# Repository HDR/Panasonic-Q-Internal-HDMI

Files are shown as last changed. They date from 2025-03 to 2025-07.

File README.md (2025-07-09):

# Panasonic Q Internal HDMI



Please consider supporting me on [ko-fi](https://ko-fi.com/martinrefseth), i generally don't make money on projects like this.

A drop-in plug & play GCPlug based HDMI mod for the Panasonic Q

# Ordering the PCB

## **With Assembly**

### PCBWay
1. Navigate to the [PCBWay Shared Projects page](https://www.pcbway.com/project/shareproject/Panasonic_Q_Drop_in_Internal_HDMI_Mod_c8eb0727.html)
2. Select `PCB+Assembly`
3. Click `Add to cart`
4. Set assembly quantity to 1 (otherwise, the assembly cost rises from 29 USD to 88 USD)
5. Select any solder mask, silkscreen, and surface finish
6. Click `Submit`

## **Without Assembly**

#### PCBWay
1. Navigate to the [PCBWay Shared Projects page](https://www.pcbway.com/project/shareproject/Panasonic_Q_Drop_in_Internal_HDMI_Mod_c8eb0727.html)
2. Select `Only PCB`
3. Select any color, silkscreen, and finish
4. Click `Submit`

#### JLCPCB
1. Navigate to [JLCPCB's order page](https://cart.jlcpcb.com/quote)
2. Click `Add gerber file` and upload `Panasonic Q Internal HDMI.zip`
3. Select 1.6mm Thickness and any color, silkscreen and finish you want

# Ordering the printed pieces
#### PCBWay
1. Navigate to the [PCBWay Shared Projects page](https://www.pcbway.com/project/shareproject/Panasonic_Q_Drop_in_Internal_HDMI_Mod_c8eb0727.html)
2. Scroll down to `CAD-Custom parts and enclosures`
3. Click the shopping cart button
4. Select `Resin`and pick your desired material
5. Change Product Desc to `DIY Entertainment >> Gaming Enclosure (HSCode:950490)`
6. Click `Submit Request`
7. Repeat for the other piece

#### JLCPCB
1. Navigate to [JLCPCB's 3D print order page](https://jlc3dp.com/3d-printing-quote)
2. Click `Add 3D Files` and select `Panasonic Q HDMI Bracket.stl` & `Panasonic Q HDMI Cover.stl`
3. Select `SLA(Resin)` and pick your desired material
4. Set 'Product description' to `Enclosure, Block, Plate, Cylinder Category -> Plastic Enclosure - HS Code 392690`
5. Click `SAVE TO CART`

# Programming
### Tools & Software Needed
- A programmer like the CH341A/B
- The CH341A Programmer Software
-  [gcvideo-3.1-gcplug.zip](https://github.com/ikorb/gcvideo/releases/tag/GCVideo-DVI_release_3.1) from ikorb's gcvideo github page
### Flashing GCVideo
1. Bridge the jumper marked JP1
2. Connect the programmer to the HDMI board according to the pinout written on the programmer and the board
3. Open CH341A Programmer
4. Press the open button and select `gcvideo-dvi-gcplug-3.1-spirom-complete.bin`
5. Select Type: `25 SPI FLASH`, Manu: `GIGADEVICE` & Name: `GD25D40`
6. Press program
7. Press verify to make sure the firmware was written correctly
8. Remove the bridge on JP1

# Parts Overview
## Hardware Parts
```
1x Panasonic Q HDMI Bracket
1x Panasonic Q HDMI Cover
2x M2x6 Screws
1x M3x8 Screw
2x M2x3x3.2mm Threaded insert
1x M3x6x4.5mm threaded insert
```

## Board Parts
| Designator | Qty | Part Number | Package | Description | LCSC Part# |
|---|-----|---|---|---|---|
| C1 | 1 | GRM155R61E225KE11D | 0402 | 2.2uF Capacitor | C385032 |
| C2 | 1 | CGA0402X5R475M250GT | 0402 | 4.7uF Capacitor | C6119795  |
| C3 | 1 | CL10A106MA8NRNC | 0603 | 10uF Capacitor | C96446 |
| C4, C5, C6, C7, C12, C13, C14 | 7 | GRM155R71H104KE14D | 0402 | 100nF Capacitor | C77020 |
| C8, C9, C10, C11 | 4 | GRM155R61E105KA12D | 0402 | 1uF Capacitor | C77009 |
| D1 | 1 | IRM-3638T | SIP-3-2.54mm | 38kHz Infrared Receiver | C16216 |
| J1 | 1 | 2086581001 | SMD | MOLEX 2086581001 HDMI Connector | C916313 |
| J2 | 1 | 1.0-22P CTSJ-H2.5 119 | SMD,P=1mm,Surface Mount，Right Angle | 22 Pin Top Contact 1mm Pitch Connector | C5373501  |
| J3 | 1 | | | 1x6 2.54mm Pin Header | |
| R1 | 1 | 0402WGJ0331TCE | 0402 | 330Ω Resistor | C12246 |
| R2 | 1 | RC0402FR-07220RL | 0402 | 220Ω Resistor | C112291 |
| R3, R4 | 2 | 0402WGJ0472TCE | 0402 | 4.7kΩ Resistor | C25940 |
| R5 | 1 | 0402WGF1800TCE | 0402 | 180Ω Resistor | C38941 |
| R6, R7 | 2 | RC0402FR-0710KL | 0402 | 10kΩ Resistor | C98220 |
| SW1 | 1 | B3U-1000P | SMD,2.5x3mm | Remote Programming Button | C231329 |
| U1 | 1 | XC3S200A-4VQG100C | TQFP-100(14x14) | XILINX FPGA | C1521645  |
| U2 | 1 | ZD25D40CNJGR | USON-8-EP(1.5x1.5) | SPI NOR Flash | C3646778  |
| U3 | 1 | SSPX3819M5-L-5-0 | SOT-23-5 | 5V Regulator | C20617302 |
| U4 | 1 | RT9013-12GB | SOT-23-5 | 1.2V Regulator | C58464 |

[**Interactive BOM**](https://martinrefseth.com/ibom/QInternalHDMI.html)

You can also upload `LCSC_BOM.xls` to [LCSC](https://www.lcsc.com/inquiry)

## Notes
- Make sure you hold the button on the board to bring up the remote programming menu BEFORE assembling your Panasonic Q (Save the settings in the menu after programming the remote)
- Cut the pin headers with a flush cutter before re-assembly, otherwise your disk assembly won't fit
- The cost with assembly from PCBWay should be around 78 USD
- HDMI output is for GC mode only
- Enhanced DVI needs to be turned on in the GCVideo settings for audio output

## Credits

ikorb - [gcvideo](https://github.com/ikorb/gcvideo)

citrus3000psi - [gcplug](https://www.reddit.com/r/Gamecube/comments/7gduxq/build_your_own_gcplug/)





https://github.com/user-attachments/assets/7356d1f4-85a7-4fde-a83c-853f3280a0fc

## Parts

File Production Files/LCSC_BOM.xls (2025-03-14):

Panasonic Q Internal HDMI Mod |  |  |  |  |  |  |  |  |  | LCSC BOM Quotation
 |  |  |  |  |  |  |  |  |  | BOM Date Created：19/02/25 02:33:42 |  |  |  | BOM Export Date: 13/03/25 04:52:43 |  |  |  | The matching result is a real-time query result, availability and prices may fluctuate. Backorder items are estimated prices for your reference, please submit "Create Quote" to get the real price. All information is provided "as is" and is subject to change without notice. Any use made of the information provided is without recourse to LCSC and at the user's risk.
 |  |  |  |  |  |  |  |  |  | EST TOTAL :$22.39 |  |  |  | Website：https://www.lcsc.com/bom | https://www.lcsc.com/bom | https://www.lcsc.com/bom | https://www.lcsc.com/bom
Uploaded data |  |  |  |  |  |  |  |  |  | LCSC Matching Results
LCSC# | Mfr. | Mrf# | Description | Package | Value | Customer Part Number | Quantity | Target Price(USD) | Target Lead Time(Business Days) | Mrf# | Mfr. | Order Qty. | Unit Price(USD) | Ext.Price(USD) | LCSC# | Package | Min | Mult | SPQ | Availability | Stock Status | Customer Notes | Description | Matched status | Product Link
C3646778 | Zetta | ZD25D40CNJGR | 4Mbit SPI 104MHz USON-8-EP(1.5x1.5) NOR FLASH ROHS | USON-8-EP(1.5x1.5) |  | - | 5 |  |  | ZD25D40CNJGR | Zetta | 5 | 0.0861 | 0.43 | C3646778 | USON-8-EP(1.5x1.5) | 5 | 5 | 3000 | 8590 | In Stock | U2 | 4Mbit SPI 104MHz USON-8-EP(1.5x1.5) NOR FLASH ROHS | Exact Matches | https://www.lcsc.com/product-detail/nor-flash_zetta-zd25d40cnjgr_C3646778.html
C916313 | MOLEX | 2086581001 | SMD HDMI Connectors ROHS | SMD |  | - | 1 |  |  | 2086581001 | MOLEX | 1 | 1.2666 | 1.27 | C916313 | SMD | 1 | 1 | 350 | 482 | In Stock | J1 | SMD HDMI Connectors ROHS | Exact Matches | https://www.lcsc.com/product-detail/hdmi-connectors_molex-2086581001_C916313.html
C16216 | Everlight Elec | IRM-3638T | 38kHz 6m 450uA 2.7V~5.5V SIP-3-2.54mm Infrared Remote Receiver (IRM) ROHS | SIP-3-2.54mm |  | - | 25 |  |  | IRM-3638T | Everlight Elec | 25 | 0.1653 | 4.13 | C16216 | SIP-3-2.54mm | 25 | 25 | 250 | 56075 | In Stock | D1 | 38kHz 6m 450uA 2.7V~5.5V SIP-3-2.54mm Infrared Remote Receiver (IRM) ROHS | Exact Matches | https://www.lcsc.com/product-detail/infrared-remote-receiver-irm_everlight-elec-irm-3638t_C16216.html
C5373501 | SHOU HAN | 1.0-22P CTSJ-H2.5 119 | Drawer Type -55â„ƒ~+85â„ƒ 22P Contact,Top Horizontal attachment 1mm SMD,P=1mm,Surface Mountï¼ŒRight Angle FFC, FPC (Flat Flexible) Connector Assemblies ROHS | SMD,P=1mm,Surface Mountï¼ŒRight Angle |  | - | 5 |  |  | 1.0-22P CTSJ-H2.5 119 | SHOU HAN | 5 | 0.1808 | 0.90 | C5373501 | SMD,P=1mm,Surface Mount，Right Angle | 5 | 5 | 20 | 790 | In Stock | J2 | Drawer Type -55℃~+85℃ 22P Contact,Top Horizontal attachment 1mm SMD,P=1mm,Surface Mount，Right Angle FFC, FPC (Flat Flexible) Connector Assemblies ROHS | Exact Matches | https://www.lcsc.com/product-detail/ffc-fpc-flat-flexible-connector-assemblies_shou-han-1-0-22p-ctsj-h2-5-119_C5373501.html
C20617302 | TECH PUBLIC | SPX3819M5-L-5-0 | 500mA 70dB@(1kHz) Fixed 5V Positive electrode SOT-23-5 Voltage Regulators - Linear, Low Drop Out (LDO) Regulators ROHS | SOT-23-5 |  | - | 5 |  |  | SPX3819M5-L-5-0 | TECH PUBLIC | 5 | 0.1223 | 0.61 | C20617302 | SOT-23-5 | 5 | 5 | 3000 | 8165 | In Stock | U3 | 500mA 70dB@(1kHz) Fixed 5V Positive electrode SOT-23-5 Voltage Regulators - Linear, Low Drop Out (LDO) Regulators ROHS | Exact Matches | https://www.lcsc.com/product-detail/voltage-regulators-linear-low-drop-out-ldo-regulators_tech-public-spx3819m5-l-5-0_C20617302.html
C58464 | Richtek Tech | RT9013-12GB | 500mA 50dB@(10kHz) Fixed 1.2V Positive electrode 5.5V SOT-23-5 Voltage Regulators - Linear, Low Drop Out (LDO) Regulators ROHS | SOT-23-5 |  | - | 5 |  |  | RT9013-12GB | Richtek Tech | 5 | 0.1366 | 0.68 | C58464 | SOT-23-5 | 5 | 5 | 3000 | 12850 | In Stock | U4 | 500mA 50dB@(10kHz) Fixed 1.2V Positive electrode 5.5V SOT-23-5 Voltage Regulators - Linear, Low Drop Out (LDO) Regulators ROHS | Exact Matches | https://www.lcsc.com/product-detail/voltage-regulators-linear-low-drop-out-ldo-regulators_richtek-tech-rt9013-12gb_C58464.html
C385032 | Murata Electronics | GRM155R61E225KE11D | 25V 2.2uF X5R Â±10% 0402 Multilayer Ceramic Capacitors MLCC - SMD/SMT ROHS | 0402 |  | - | 50 |  |  | GRM155R61E225KE11D | Murata Electronics | 50 | 0.0185 | 0.93 | C385032 | 0402 | 50 | 50 | 10000 | 353050 | In Stock | C1 | 25V 2.2uF X5R ±10% 0402 Multilayer Ceramic Capacitors MLCC - SMD/SMT ROHS | Exact Matches | https://www.lcsc.com/product-detail/multilayer-ceramic-capacitors-mlcc-smd-smt_murata-electronics-grm155r61e225ke11d_C385032.html
C6119795 | HRE | CGA0402X5R475M250GT | 25V 4.7uF X5R Â±20% 0402 Multilayer Ceramic Capacitors MLCC - SMD/SMT ROHS | 0402 |  | - | 50 |  |  | CGA0402X5R475M250GT | HRE | 50 | 0.0128 | 0.64 | C6119795 | 0402 | 50 | 50 | 10000 | 379000 | In Stock | C2 | 25V 4.7uF X5R ±20% 0402 Multilayer Ceramic Capacitors MLCC - SMD/SMT ROHS | Exact Matches | https://www.lcsc.com/product-detail/multilayer-ceramic-capacitors-mlcc-smd-smt_hre-cga0402x5r475m250gt_C6119795.html
C96446 | Samsung Electro-Mechanics | CL10A106MA8NRNC | 25V 10uF X5R Â±20% 0603 Multilayer Ceramic Capacitors MLCC - SMD/SMT ROHS | 0603 |  | - | 20 |  |  | CL10A106MA8NRNC | Samsung Electro-Mechanics | 20 | 0.0151 | 0.30 | C96446 | 0603 | 20 | 20 | 4000 | 1307720 | In Stock | C3 | 25V 10uF X5R ±20% 0603 Multilayer Ceramic Capacitors MLCC - SMD/SMT ROHS | Exact Matches | https://www.lcsc.com/product-detail/multilayer-ceramic-capacitors-mlcc-smd-smt_samsung-electro-mechanics-cl10a106ma8nrnc_C96446.html
C77020 | Murata Electronics | GRM155R71H104KE14D | 50V 100nF X7R Â±10% 0402 Multilayer Ceramic Capacitors MLCC - SMD/SMT ROHS | 0402 |  | - | 100 |  |  | GRM155R71H104KE14D | Murata Electronics | 100 | 0.0032 | 0.32 | C77020 | 0402 | 100 | 100 | 10000 | 6570400 | In Stock | C4,C5,C6,C7,C12,C13,C14 | 50V 100nF X7R ±10% 0402 Multilayer Ceramic Capacitors MLCC - SMD/SMT ROHS | Exact Matches | https://www.lcsc.com/product-detail/multilayer-ceramic-capacitors-mlcc-smd-smt_murata-electronics-grm155r71h104ke14d_C77020.html
C77009 | Murata Electronics | GRM155R61E105KA12D | 25V 1uF X5R Â±10% 0402 Multilayer Ceramic Capacitors MLCC - SMD/SMT ROHS | 0402 |  | - | 100 |  |  | GRM155R61E105KA12D | Murata Electronics | 100 | 0.0053 | 0.53 | C77009 | 0402 | 100 | 100 | 10000 | 640500 | In Stock | C8,C9,C10,C11 | 25V 1uF X5R ±10% 0402 Multilayer Ceramic Capacitors MLCC - SMD/SMT ROHS | Exact Matches | https://www.lcsc.com/product-detail/multilayer-ceramic-capacitors-mlcc-smd-smt_murata-electronics-grm155r61e105ka12d_C77009.html
C12246 | UNI-ROYAL(Uniroyal Elec) | 0402WGJ0331TCE | 62.5mW Thick Film Resistors 50V Â±100ppm/â„ƒ Â±5% 330Î© 0402 Chip Resistor - Surface Mount ROHS | 0402 |  | - | 100 |  |  | 0402WGJ0331TCE | UNI-ROYAL(Uniroyal Elec) | 100 | 0.0005 | 0.05 | C12246 | 0402 | 100 | 100 | 10000 | 286700 | In Stock | R1 | 1/16W Thick Film Resistors 50V ±100ppm/℃ ±5% 330Ω 0402 Chip Resistor - Surface Mount ROHS | Exact Matches | https://www.lcsc.com/product-detail/chip-resistor-surface-mount_uni-royal-uniroyal-elec-0402wgj0331tce_C12246.html
C112291 | YAGEO | RC0402FR-07220RL | 62.5mW Thick Film Resistors 50V Â±100ppm/â„ƒ Â±1% 220Î© 0402 Chip Resistor - Surface Mount ROHS | 0402 |  | - | 100 |  |  | RC0402FR-07220RL | YAGEO | 100 | 0.0007 | 0.07 | C112291 | 0402 | 100 | 100 | 10000 | 818900 | In Stock | R2 | 62.5mW Thick Film Resistors 50V ±100ppm/℃ ±1% 220Ω 0402 Chip Resistor - Surface Mount ROHS | Exact Matches | https://www.lcsc.com/product-detail/chip-resistor-surface-mount_yageo-rc0402fr-07220rl_C112291.html
C25940 | UNI-ROYAL(Uniroyal Elec) | 0402WGJ0472TCE | 62.5mW Thick Film Resistors 50V Â±100ppm/â„ƒ Â±5% 4.7kÎ© 0402 Chip Resistor - Surface Mount ROHS | 0402 |  | - | 100 |  |  | 0402WGJ0472TCE | UNI-ROYAL(Uniroyal Elec) | 100 | 0.0005 | 0.05 | C25940 | 0402 | 100 | 100 | 10000 | 1585300 | In Stock | R3,R4 | 1/16W Thick Film Resistors 50V ±100ppm/℃ ±5% 4.7kΩ 0402 Chip Resistor - Surface Mount ROHS | Exact Matches | https://www.lcsc.com/product-detail/chip-resistor-surface-mount_uni-royal-uniroyal-elec-0402wgj0472tce_C25940.html
C38941 | UNI-ROYAL(Uniroyal Elec) | 0402WGF1800TCE | 62.5mW Thick Film Resistors 50V Â±100ppm/â„ƒ Â±1% 180Î© 0402 Chip Resistor - Surface Mount ROHS | 0402 |  | - | 100 |  |  | 0402WGF1800TCE | UNI-ROYAL(Uniroyal Elec) | 100 | 0.0006 | 0.06 | C38941 | 0402 | 100 | 100 | 10000 | 183000 | In Stock | R5 | 1/16W Thick Film Resistors 50V ±100ppm/℃ ±1% 180Ω 0402 Chip Resistor - Surface Mount ROHS | Exact Matches | https://www.lcsc.com/product-detail/chip-resistor-surface-mount_uni-royal-uniroyal-elec-0402wgf1800tce_C38941.html
C60490 | YAGEO | RC0402FR-0710KL | 62.5mW Thick Film Resistors 50V Â±100ppm/â„ƒ Â±1% 10kÎ© 0402 Chip Resistor - Surface Mount ROHS | 0402 |  | - | 100 |  |  | RC0402FR-0710KL | YAGEO | 100 | 0.0006 | 0.06 | C60490 | 0402 | 100 | 100 | 10000 | 14827900 | In Stock | R6,R7 | 62.5mW Thick Film Resistors 50V ±100ppm/℃ ±1% 10kΩ 0402 Chip Resistor - Surface Mount ROHS | Exact Matches | https://www.lcsc.com/product-detail/chip-resistor-surface-mount_yageo-rc0402fr-0710kl_C60490.html
C1521645 | AMD/XILINX | XC3S200A-4VQG100C | TQFP-100(14x14) Programmable Logic Device (CPLDs/FPGAs) ROHS | TQFP-100(14x14) |  | - | 1 |  |  | XC3S200A-4VQG100C | AMD/XILINX | 1 | 10.5574 | 10.56 | C1521645 | TQFP-100(14x14) | 1 | 1 | 90 | 104 | In Stock | U1 | TQFP-100(14x14) Programmable Logic Device (CPLDs/FPGAs) ROHS | Exact Matches | https://www.lcsc.com/product-detail/programmable-logic-device-cplds-fpgas_amd-xilinx-xc3s200a-4vqg100c_C1521645.html
 |  |  |  |  |  | - | 5 |  |  | B3U-1000P | Omron Electronics | 5 | 0.1604 | 0.80 | C231329 | SMD,2.5x3mm | 5 | 5 | 3500 | 60515 | In Stock | SW1 | 2.5mm 1.6mm Round Button 50mA Standing paste 3mm SPST 153gf 12V SMD,2.5x3mm Tactile Switches ROHS | Exact Matches | https://www.lcsc.com/product-detail/tactile-switches_omron-electronics-b3u-1000p_C231329.html

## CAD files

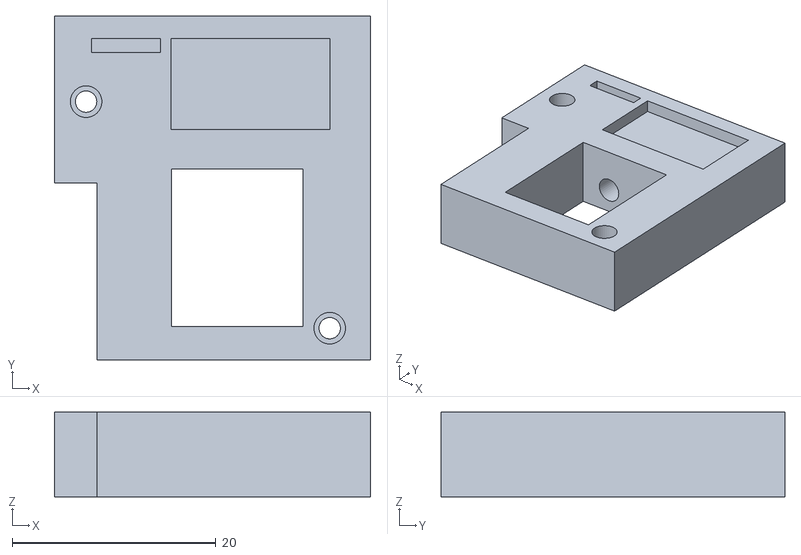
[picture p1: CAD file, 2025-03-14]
Printed Pieces/Panasonic Q HDMI Bracket.stl
31.0 x 33.7 x 8.30

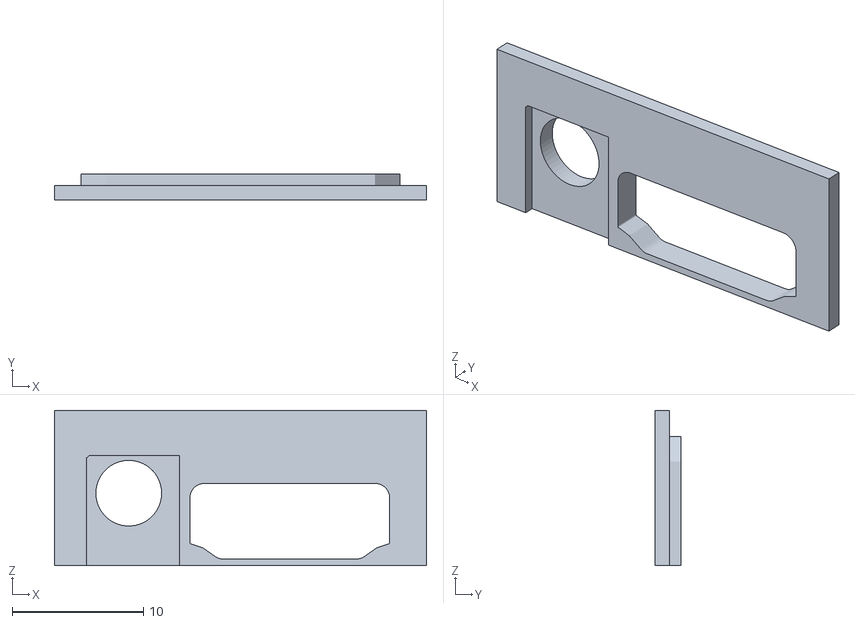
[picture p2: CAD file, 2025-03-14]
Printed Pieces/Panasonic Q HDMI Cover.stl
28.3 x 2.00 x 11.8

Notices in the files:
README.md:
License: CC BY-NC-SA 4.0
